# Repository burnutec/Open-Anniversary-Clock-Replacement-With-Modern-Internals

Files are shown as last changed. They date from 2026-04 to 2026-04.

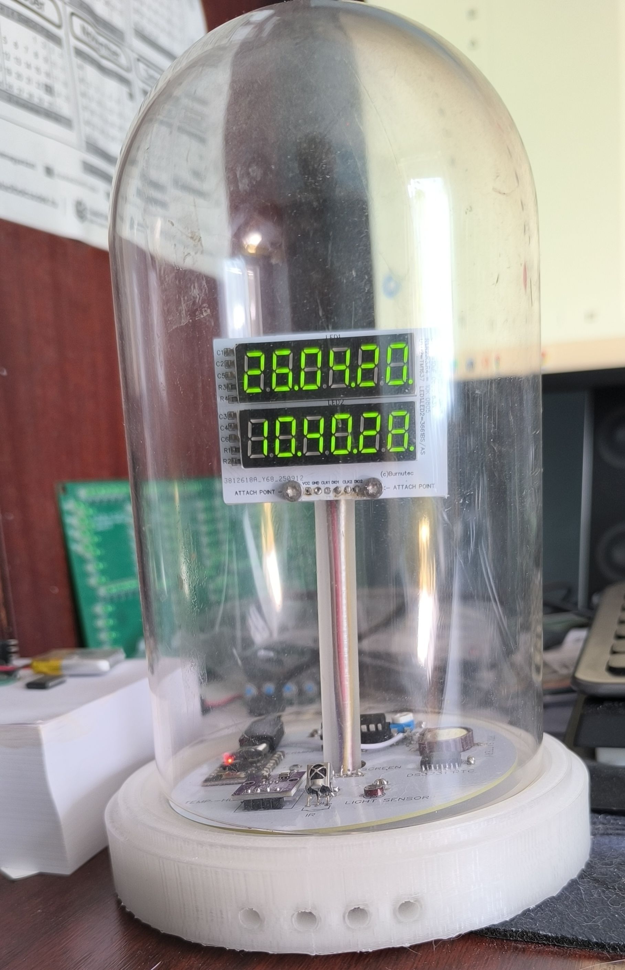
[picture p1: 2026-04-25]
9bbda89c12d18abac0bc867cbccf6303.jpg

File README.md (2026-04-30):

# Open-Anniversary-Clock-Replacement-With-Modern-Internals

DISCLAIMER:
The modifications you do to your equipment , i can not be held responsible for.
The software and models are provied free of charge , what you do with them i can not be held responsible for.
This is a hobby project i decided to share , comes without any warranties.

So after reading this lets begin:

Originally Called The Floating Display Clock
Because in the dark all you can see is the 2 displays , yes it has 2 , that gives more possibilities in terms of use and displaying information.
The parts make out the housing are printed with transparent PLA for the same reason , to be invisble :).

Keep in mind , i'm not a 3d design expert , nor a programmer , or electrical engineer.
More a hobbist maker - developer - technician.

This project is aimed at creating all the internals for a  replacement clock , made to fit inside a middle sized clock dome , wheter it is acrylic or glass , its up to you in the finishing touches. 
The electronics are designed to be as cheap and available as possible , with the exception of the melody chip, that is obtainable , but availablility is somewhat in debate.
The chip HK221-2 is from a company Honistak in taiwan , and currenty in production , obtaining it will still be challenging if not bought in quantity.
The chip seems to be a clone / reproduction of the UM3482A which is also from a Taiwanese company UMC from the early 90's. I have chosen this chip because it has retrigger input and very few support components.
The chips used for development are obtined from this website: https://www.budgetronics.eu/en/ics/special-use-ics/multi-tunes-melody-ic-hk221-2/a-6563-10000142
The brains of the operation is the ESP32-C3 Supermini , which is widely available , and cheap but capable.
Sensors are AHT20+BMP280 module , also readily available internet wide.
For Light sensing , GL5528 is used in a resitor divider configuration.
RTC the legendary DS3231 , yes no crystals needed and accurate enough for longer timekeeping compared to the DS1307 most pepole use. RTC battery is CR1220 for compactness.
A simple one tramsistor amplifier is used for playing the molodies from the HK221-2 , with an 8R 0.5W speaker is an ideal choice in 50mm diameter.
RT9013-33GB used for voltage regulation , small cheap and widely available.
Two TM1637 LED display driver for the screens.
The clock has no keys or buttons , all inputs handled with IR remote control. VS1838 compatible receiver used to decode the remote control commands.

Current fucntions:

- Display Time 
- Display Date
- Display in 12 / 24HR format
- Display Temperature 
- Display Humidity 
- Display Air pressure
- Display Currently set Time mode 12/24HR
- Display Week number
- Manual brightness setting 1-7
- Automatic Brightness setting ( Based on environmental light ) - Can be set to ON/OFF
- Hourly Chime  - Can be set to ON / OFF
- WIFI clock sync using NTP , requires setup , toggled from Remote control.
- Check for Alarm 1 or 2 is ON or OFF

In development : Alarm function

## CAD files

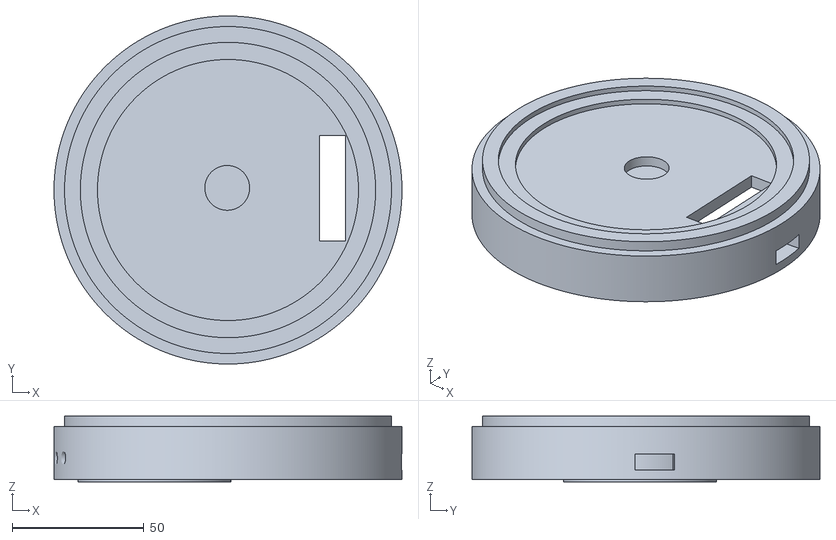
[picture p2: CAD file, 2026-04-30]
pcb holder-mk3.stl
132.0 x 132.0 x 25.0

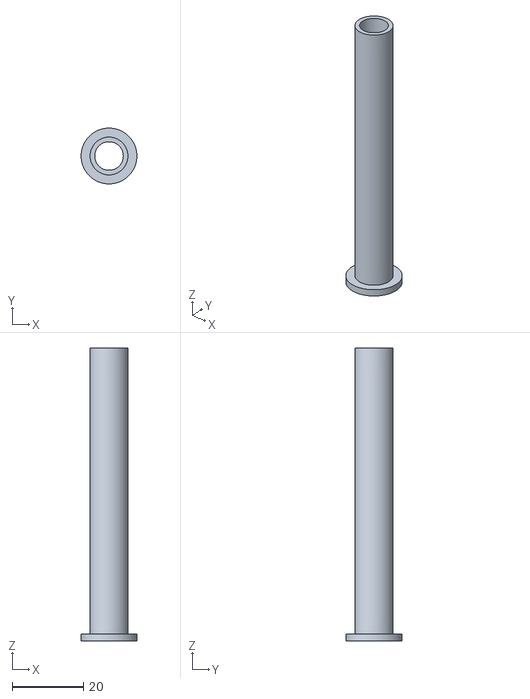
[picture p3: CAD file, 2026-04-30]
Display-Holder.stl
15.6 x 15.6 x 82.0

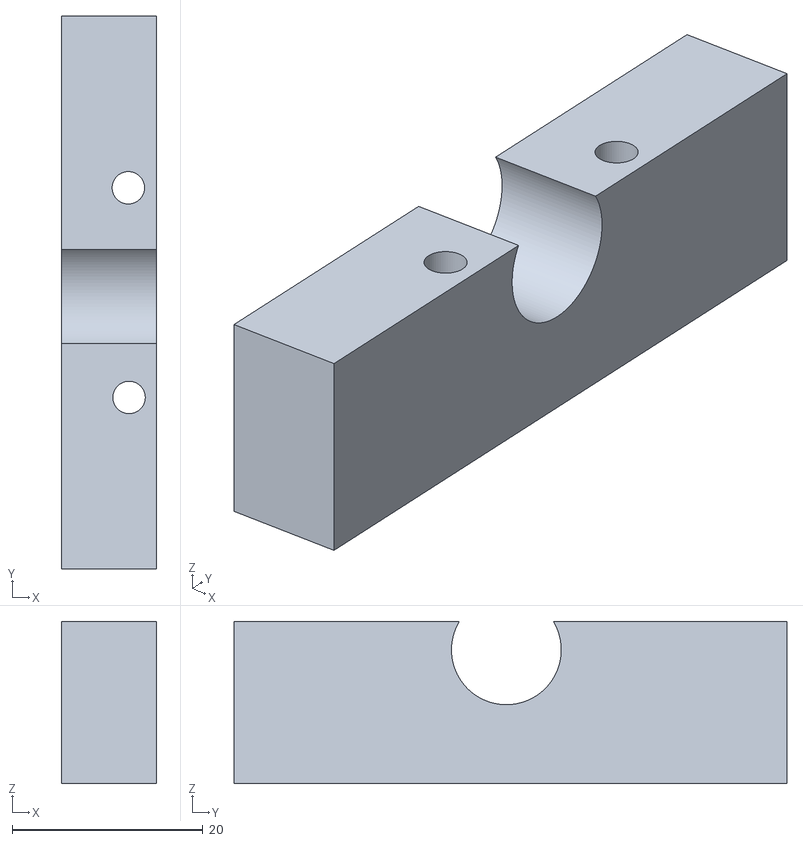
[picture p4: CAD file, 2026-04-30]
display-bracket.stl
10.0 x 58.0 x 17.0

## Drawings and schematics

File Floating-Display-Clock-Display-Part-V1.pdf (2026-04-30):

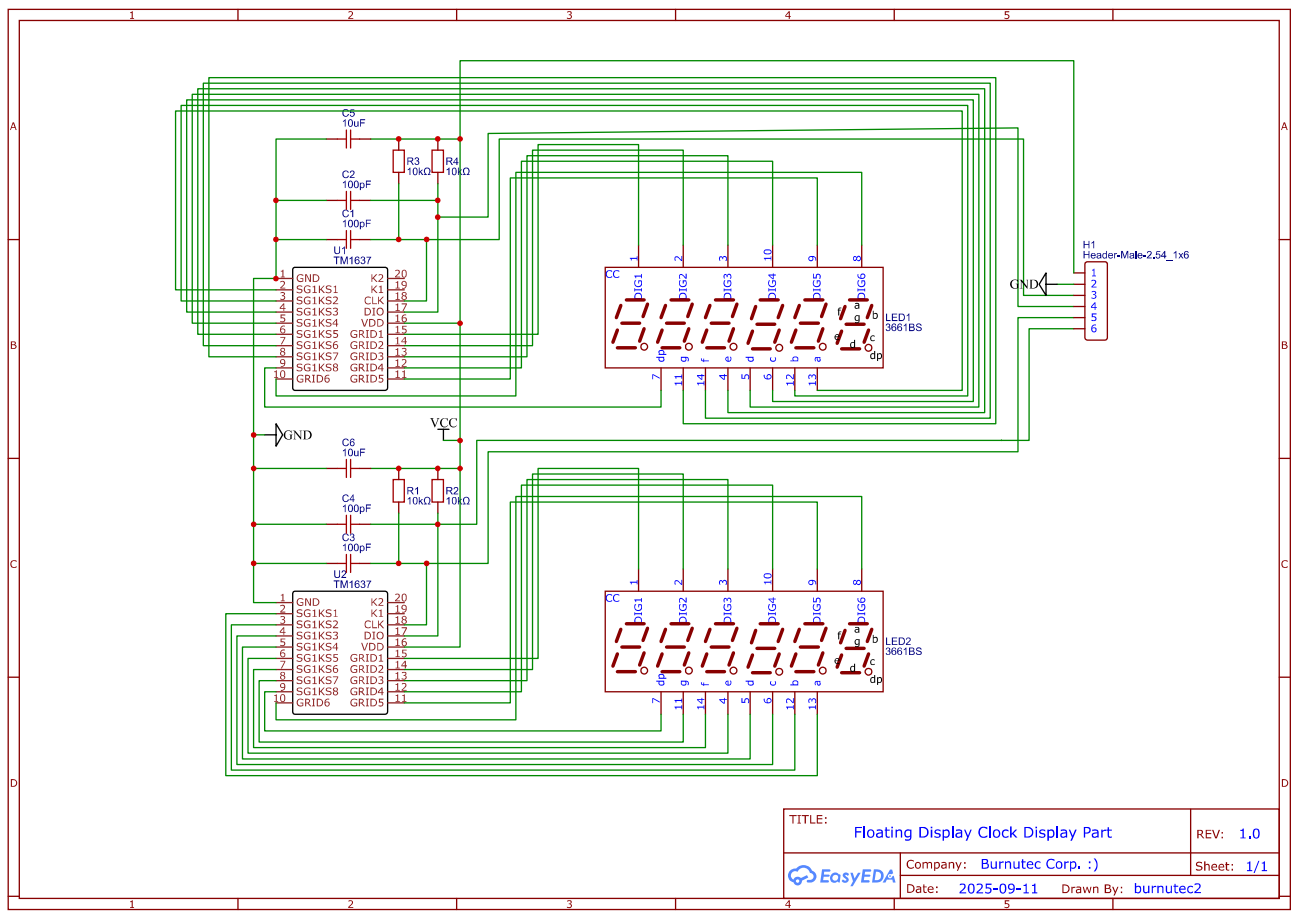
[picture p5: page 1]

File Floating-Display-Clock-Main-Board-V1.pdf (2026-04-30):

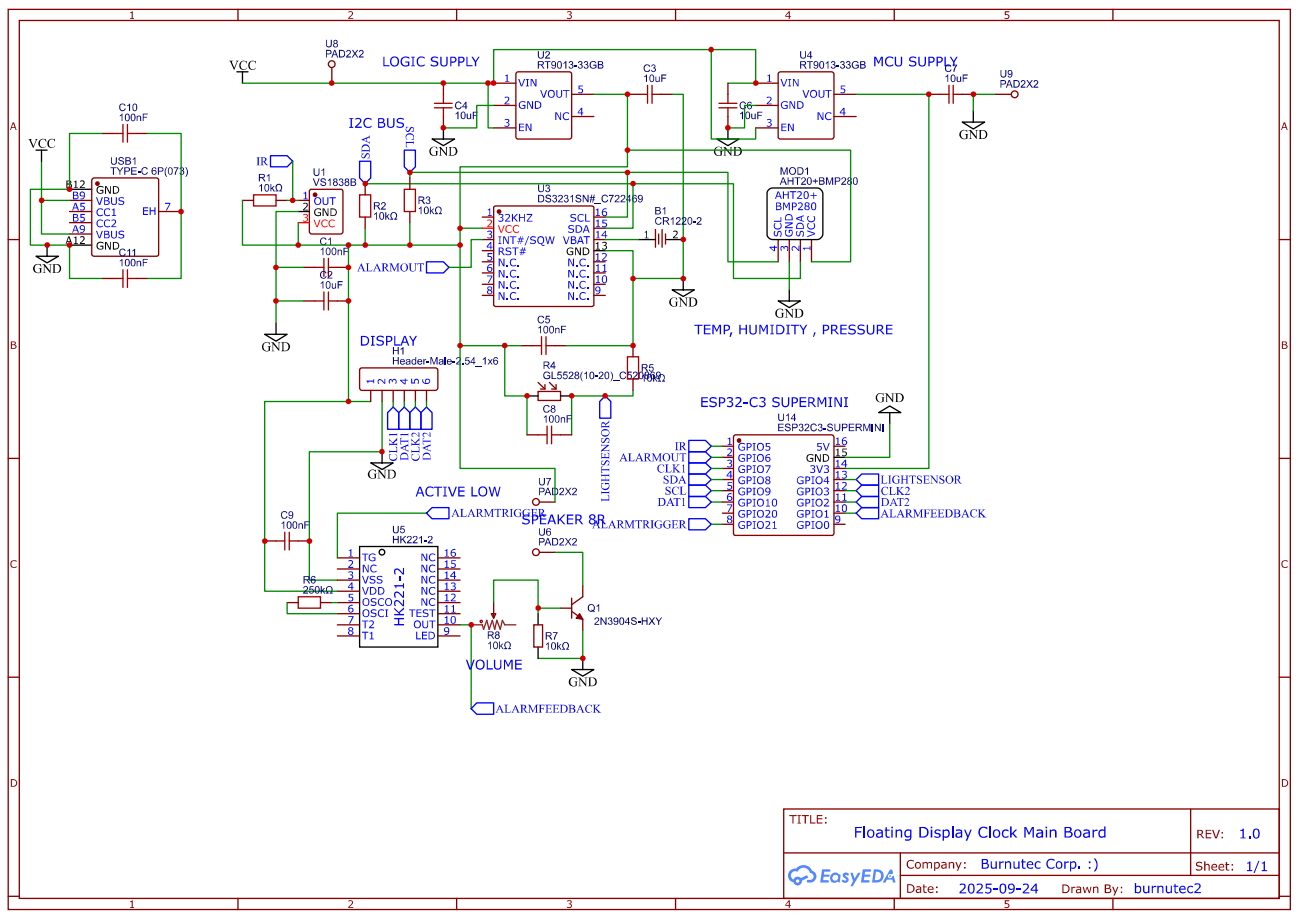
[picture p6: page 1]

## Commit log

2026-04-30 Project file in Autodesk 123D For Display Bracket
2026-04-30 Display Bracket STL ready to print
    [display-bracket.stl]
2026-04-30 Project file in Autodesk 123D For Display Holder Tube
2026-04-30 Display Holder STL ready to print
    [Display-Holder.stl]
2026-04-30 Project file in Autodesk 123D For Pcb Holder - Base
2026-04-30 Pcb Holder - Base STL ready to print
    [pcb holder-mk3.stl]
2026-04-30 Pcb Gerber files For the Screen Part
2026-04-30 Gerber File For Main Board
2026-04-30 Main Board Schematic Original Exported From EasyEDA
2026-04-30 Display Board Schematic Original Exported From EasyEDA
